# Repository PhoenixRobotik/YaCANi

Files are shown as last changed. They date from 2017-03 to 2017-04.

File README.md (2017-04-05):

# YaCANi: Yet another CAN interface

The YaCANi is forked from the [CANtact project](https://github.com/CANtact/cantact-hw).  
The goal was a smaller PCB with micro USB and a specific CAN connector (JST XH). Some components have also been replaced by components we use on our other projects.

It have been designed with [KiCad](http://www.kicad-pcb.org/).

You might be interested in others forks of [CANtact project](https://github.com/CANtact/cantact-hw):
- [Canable](http://canable.io/): smaller PCB than CANtact, designed on Eagle CAD (we took a lot of inspiration from it)
- [x893's fork](https://github.com/x893/cantact-hw): uses ADM3053 CAN transceiver (for it's isolation capability)

## License

Hardware files released under the [Creative Commons Attribution-ShareAlike 4.0
International License](http://creativecommons.org/licenses/by-sa/4.0/) 
(CC BY-SA 4.0)

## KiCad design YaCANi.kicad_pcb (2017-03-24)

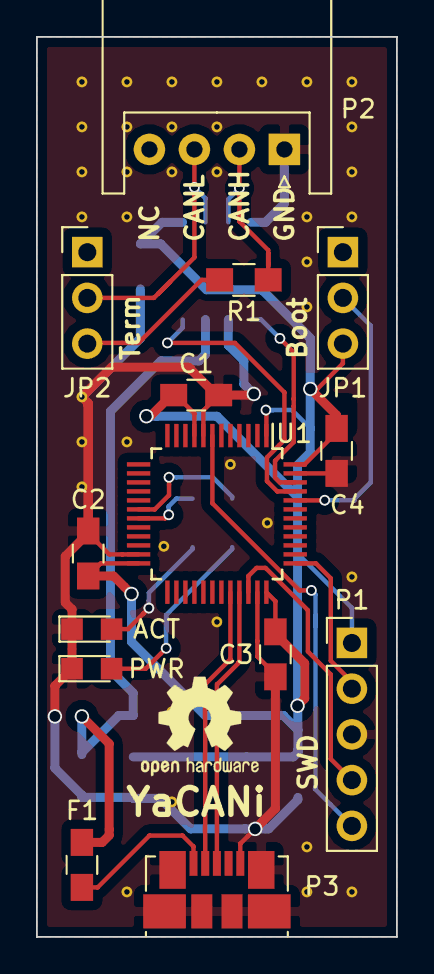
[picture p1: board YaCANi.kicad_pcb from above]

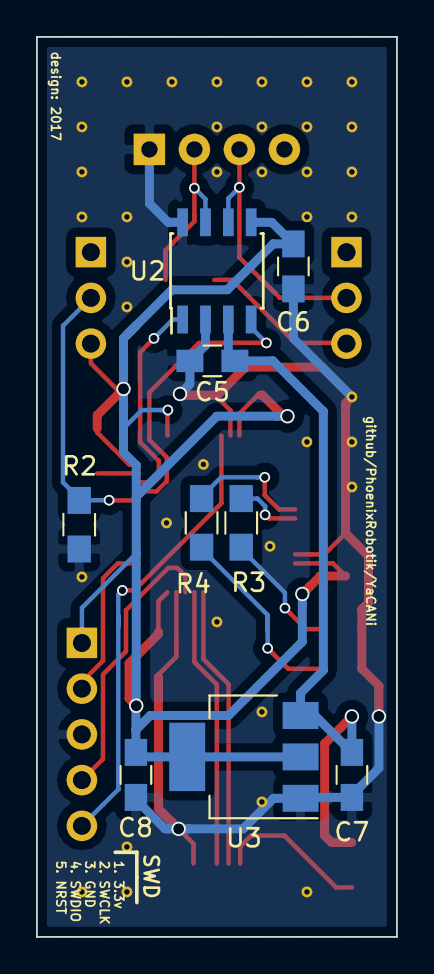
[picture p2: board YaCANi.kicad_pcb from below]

Board: 2 copper layers, 20.0 x 50.0 mm, 23 parts (9 on the bottom side), 19 nets.

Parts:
ACT: LED-RED; LED_0805
C1, C2, C4, C5, C6: 0.1uF; C_0805_HandSoldering
C3: 1uF; C_0805_HandSoldering
C7: 100nF; C_0805_HandSoldering
C8: 10uF; C_0805_HandSoldering
F1: Polyfuse; C_0805_HandSoldering
JP1, JP2: Jumper_NC_Dual; Pin_Header_Straight_1x03_Pitch2.54mm
P1: SWD; Pin_Header_Straight_1x05_Pitch2.54mm
P2: CAN; JST_XH_S04B-XH-A_04x2.50mm_Angled
P3: USB; USB_Micro-B_Molex_47346-0001
PWR: LED-GREEN; LED_0805
R1: 120; R_0805_HandSoldering
R2: 10k; R_0805_HandSoldering
R3, R4: R; R_0805_HandSoldering
U1: STM32F042C6T6; LQFP-48_7x7mm_Pitch0.5mm
U2: MCP2562-E/SN; SOIC-8_3.9x4.9mm_Pitch1.27mm
U3: LD1117S33TR; SOT-223

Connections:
+3V3: C1.1, C2.1, C3.1, C4.1, C6.2, C8.1, JP1.3, P1.1, U1.1, U1.9, U1.24, U1.36, U1.48, U2.5, U3.2
+5V: C5.2, C7.1, F1.2, U2.3, U3.3
/CAN_RX: U1.45, U2.4
/CAN_TX: U1.46, U2.1
/NRST: P1.5, U1.7
/SWCLK: P1.2, U1.37
/SWDIO: P1.4, U1.34
/USB_DM: P3.2, U1.32
/USB_DP: P3.3, U1.33
BOOT0: JP1.2, R2.1, U1.44
CAN_H: P2.2, R1.2, U2.7
CAN_L: JP2.2, P2.3, U2.6
GND: ACT.1, C1.2, C2.2, C3.2, C4.2, C5.1, C6.1, C7.2, C8.2, P1.3, P2.1, P3.5, P3.6, PWR.1, R2.2, U1.8, U1.23, U1.35, U1.47, U2.2, U2.8, U3.1
LED_ACT: R3.2, U1.19
LED_PWR: R4.2, U1.18
unnamed: ACT.2, R3.1
unnamed: PWR.2, R4.1
unnamed: F1.1, P3.1
unnamed: JP2.3, R1.1

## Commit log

2017-03-20 remove gerbers
    [cantact-bom-v1_0.xls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]
2017-03-20 remove BOM
2017-03-20 rename files
    [YaCANi.kicad_pcb, YaCANi.sch]
2017-03-20 updated libs, footprints
    [YaCANi.kicad_pcb, YaCANi.sch]
2017-03-20 correct USB connector
2017-03-23 add USB 5v fuse
    [YaCANi.sch]
2017-03-23 change MCP2561 for MCP2562
    [YaCANi.sch]
2017-03-23 replace DB9 connector with JST-XH and add 120ohm resistor jumper
    [YaCANi.sch]
2017-03-23 add boot jumper
    [YaCANi.sch]
2017-03-23 remove 16MHz crystal
    [YaCANi.sch]
2017-03-23 change regulator
    [YaCANi.sch]
2017-03-23 move LED and change logic
    [YaCANi.sch]
2017-03-23 add some text on schematic
    [YaCANi.sch]
2017-03-23 change LED labels
    [YaCANi.sch]
2017-03-23 remove some decoupling capacitors (ouch !) + numbering
    [YaCANi.sch]
2017-03-23 just some formating
    [YaCANi.sch]
2017-03-23 new footprints on pcb
    [YaCANi.kicad_pcb]
2017-03-24 correct missing connection
    [YaCANi.sch]
2017-03-24 correct wrong connection
    [YaCANi.sch]
2017-03-24 first placement and quick routing
    [YaCANi.kicad_pcb, YaCANi.sch]
2017-03-24 just change a via
    [YaCANi.kicad_pcb]
2017-03-24 remove test points
    [YaCANi.kicad_pcb, YaCANi.sch]
2017-03-24 proper track size
    [YaCANi.kicad_pcb]
2017-03-24 DRC ok
    [YaCANi.kicad_pcb]
2017-03-24 first version ?
    [YaCANi.kicad_pcb]
2017-03-24 remove useless via
    [YaCANi.kicad_pcb]
2017-03-24 change CAN connector to an angled version
    [YaCANi.kicad_pcb, YaCANi.sch]
2017-03-24 move CAN connector
    [YaCANi.kicad_pcb]
2017-03-24 add text on board
    [YaCANi.kicad_pcb, YaCANi.sch]
2017-03-24 add logo and referencies
    [YaCANi.kicad_pcb]
2017-03-24 add LED labelling
    [YaCANi.kicad_pcb]
2017-03-24 add design date
    [YaCANi.kicad_pcb]
